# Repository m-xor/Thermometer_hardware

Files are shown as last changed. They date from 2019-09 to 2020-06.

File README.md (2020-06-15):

# Thermometer_hardware

PCBs designed for ZS60 universal case https://www.tme.eu/pl/details/z60-abs/obudowy-z-panelem/kradex/z60-abs/
The device consists of three PCB:
- LCD display board
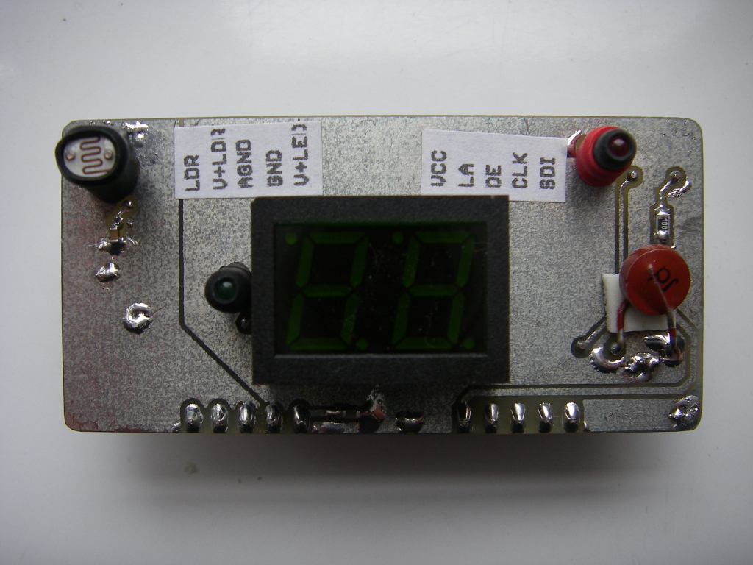
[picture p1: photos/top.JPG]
PCB top

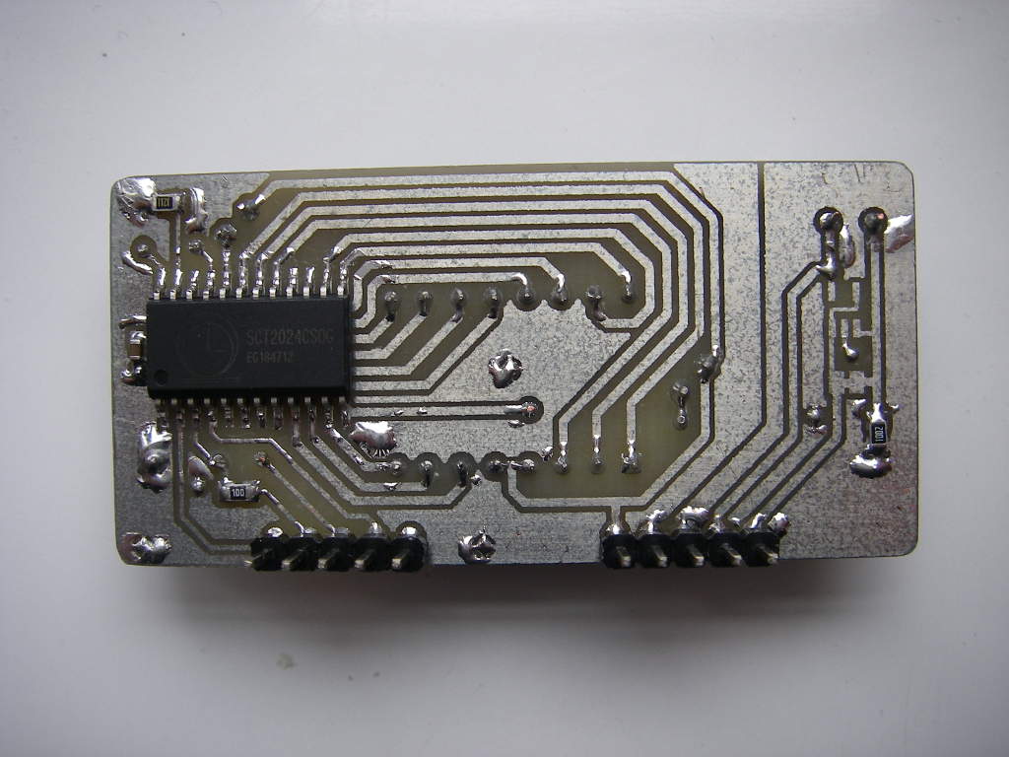
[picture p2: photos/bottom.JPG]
PCB bottom

- main board
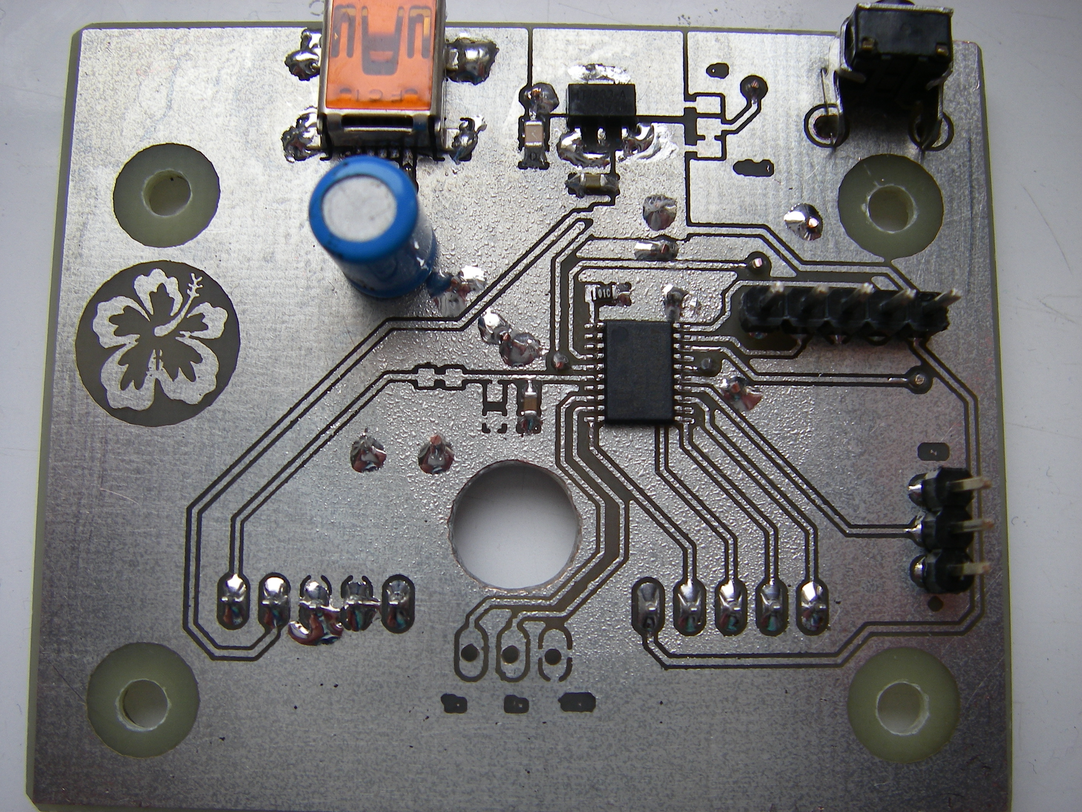
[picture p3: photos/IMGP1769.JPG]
Main board top

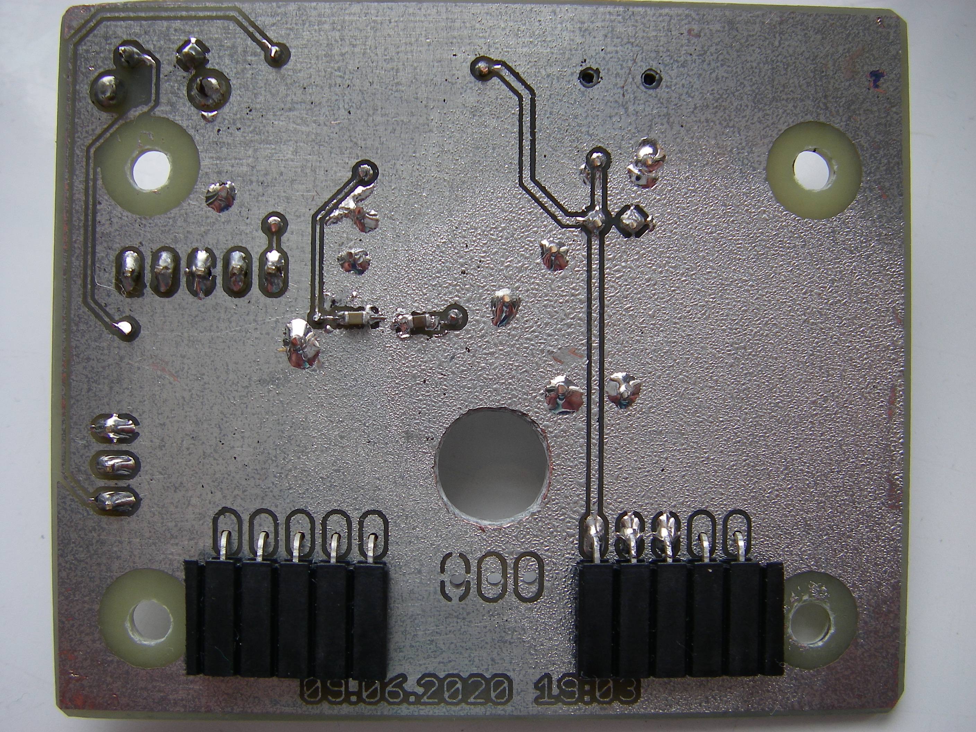
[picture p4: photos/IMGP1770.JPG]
Main board bottom

- receiver board
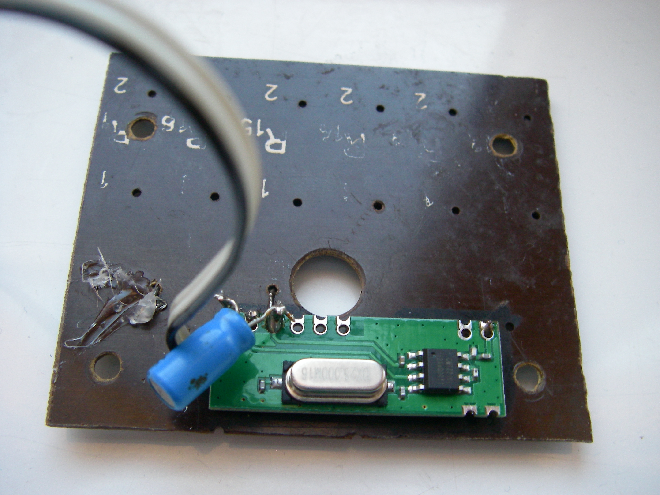
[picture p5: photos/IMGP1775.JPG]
Receiver board top

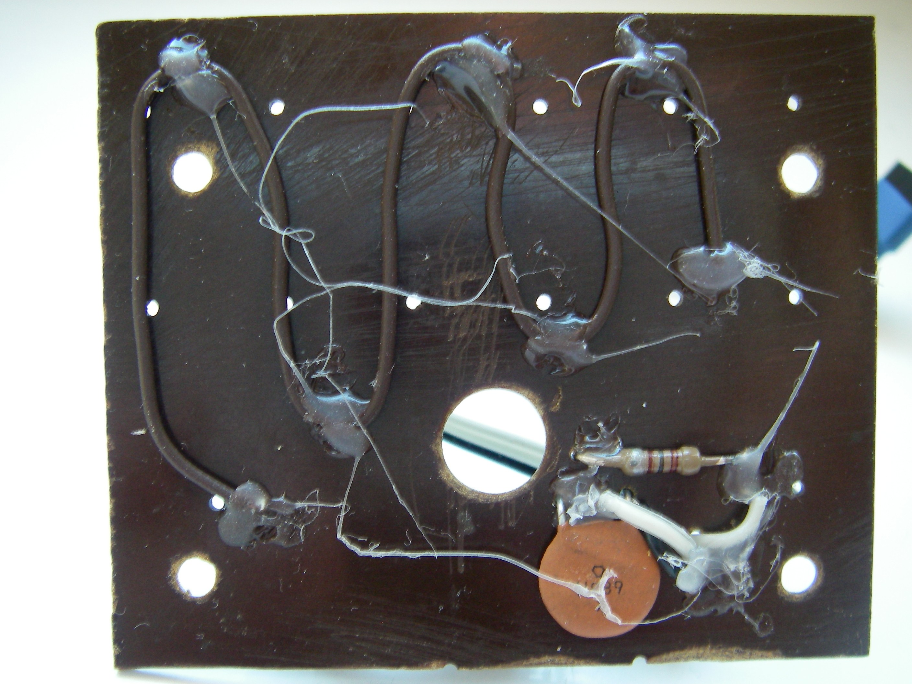
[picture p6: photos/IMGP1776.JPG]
Receiver board bottom

- The device
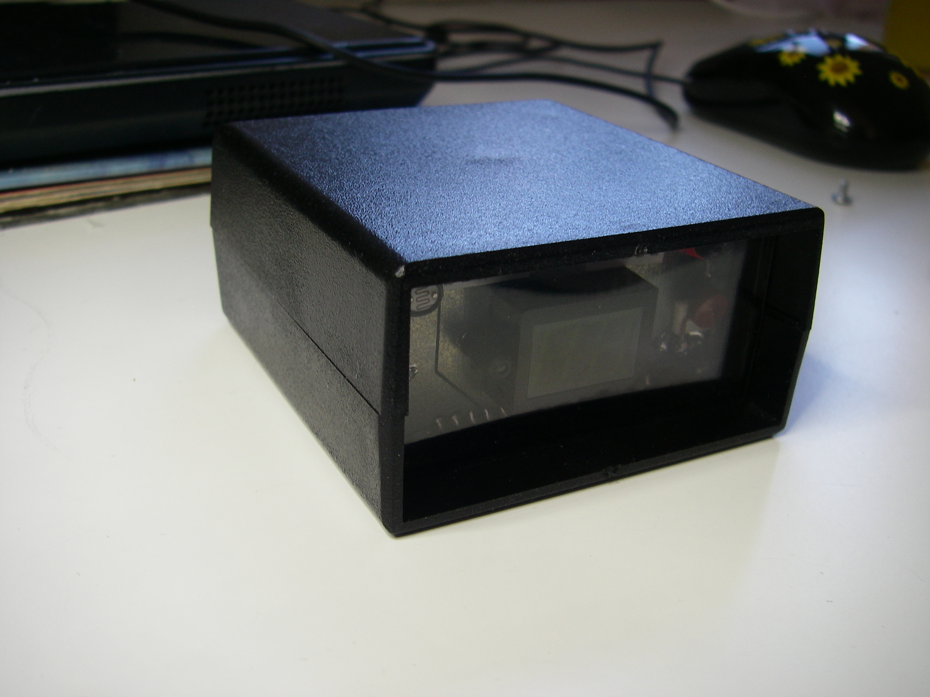
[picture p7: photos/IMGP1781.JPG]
Device


Firmware: https://github.com/m-xor/Thermometer_receiver

- Known issues
 * power socket is placed to deep
 * PA9, PA10 could be routed to solder pads in case of need accessing bootloader

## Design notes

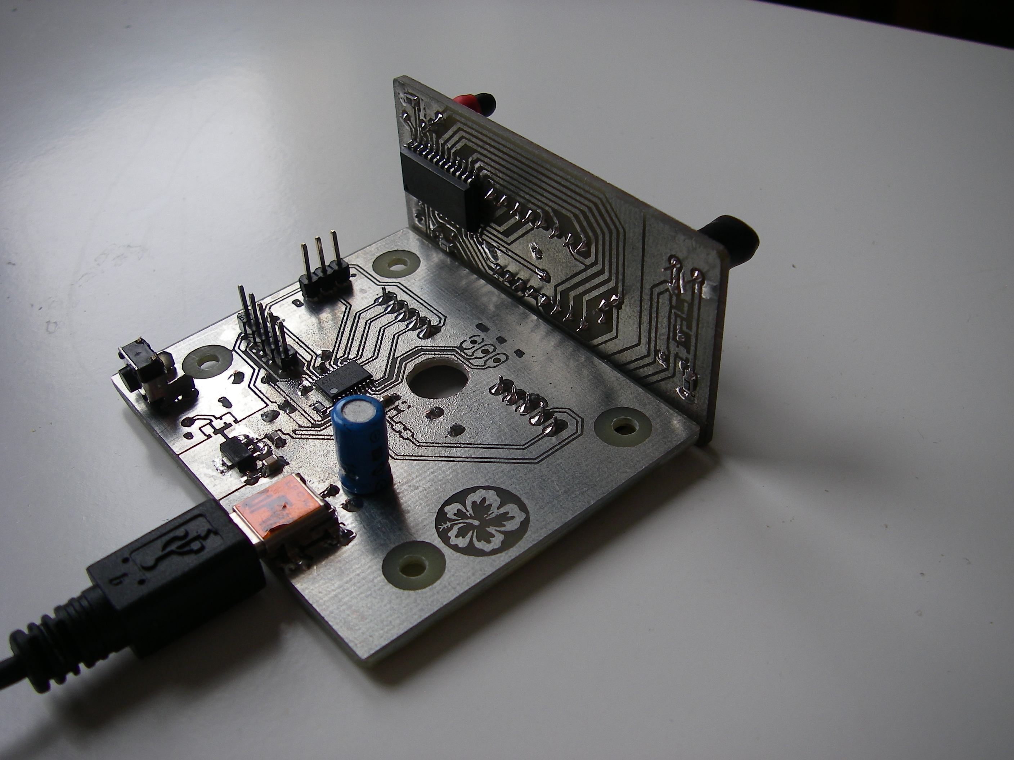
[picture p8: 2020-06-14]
photos/IMGP1772.JPG

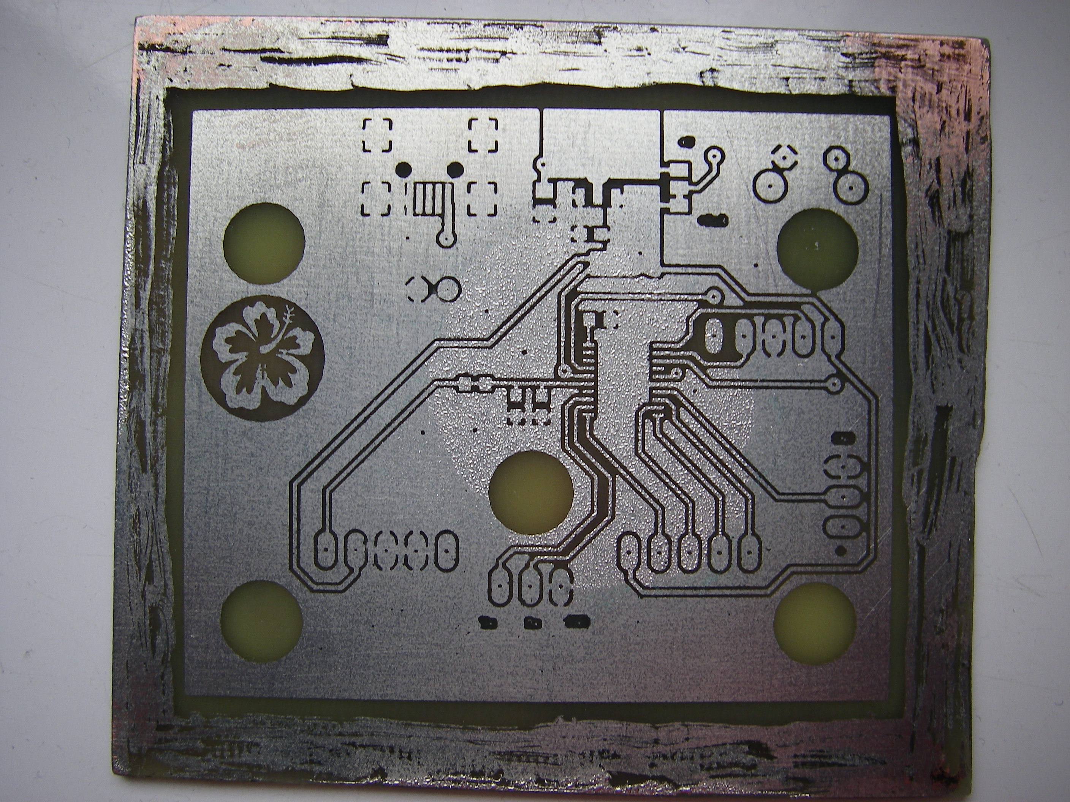
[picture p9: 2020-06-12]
photos/IMGP1759.JPG

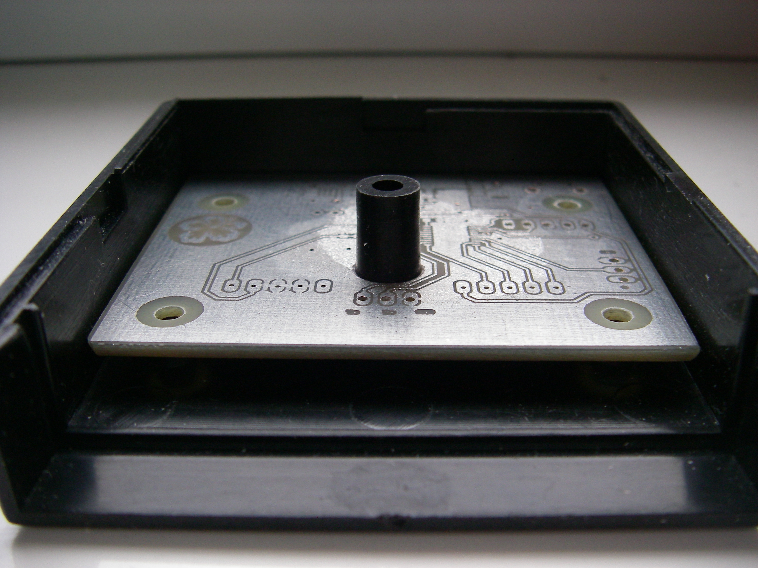
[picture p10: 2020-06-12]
photos/IMGP1766.JPG

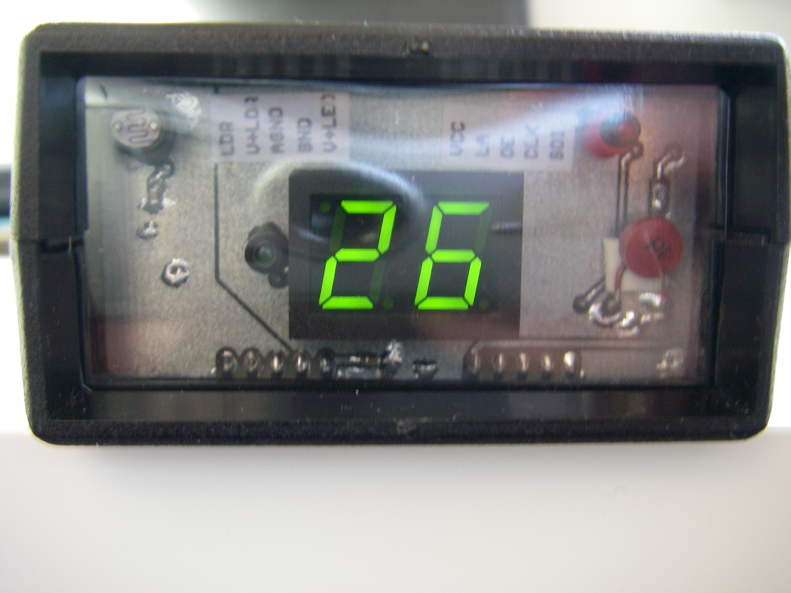
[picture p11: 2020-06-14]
photos/IMGP1783.JPG

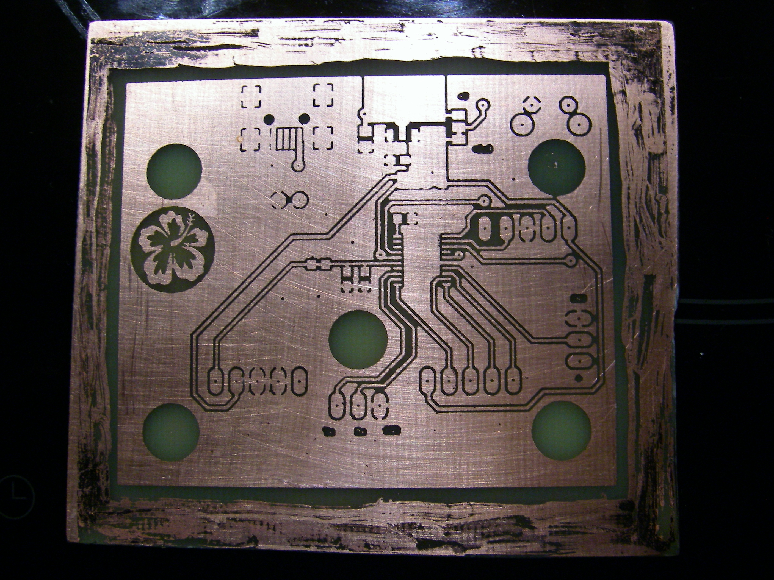
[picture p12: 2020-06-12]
photos/IMGP1753.JPG

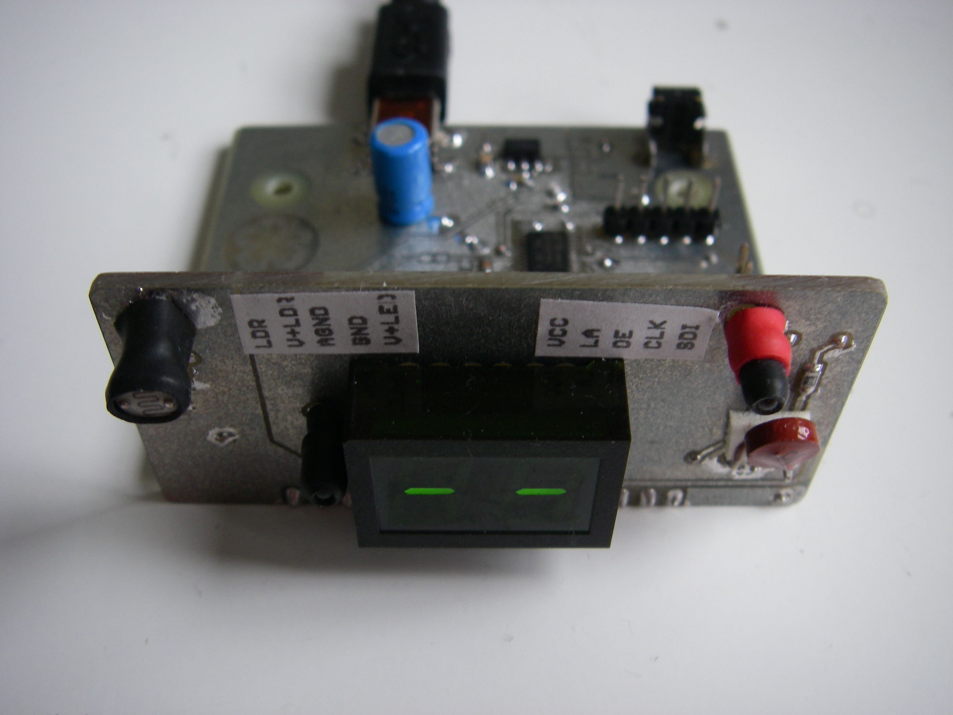
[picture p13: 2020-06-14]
photos/IMGP1771.JPG

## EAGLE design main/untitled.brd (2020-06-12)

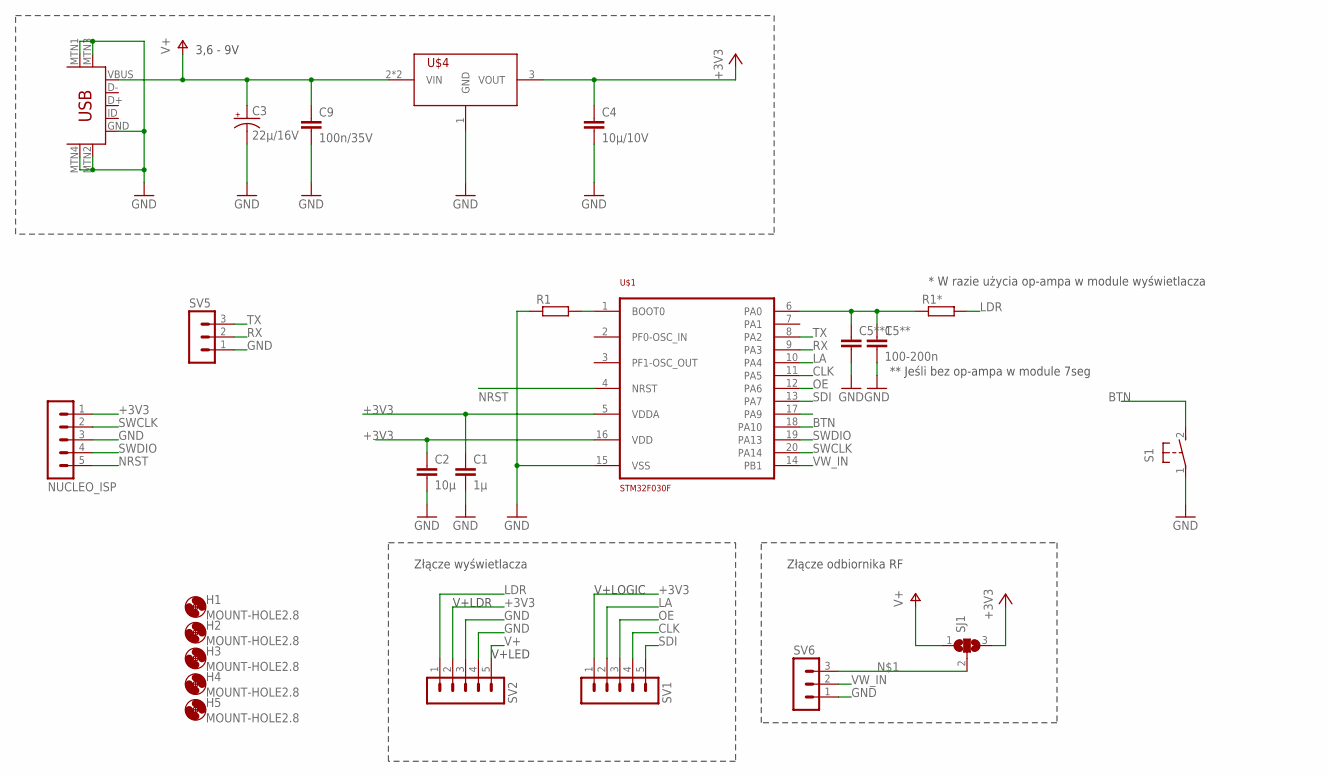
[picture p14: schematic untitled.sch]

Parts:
C1: 1µ; C0603
C2: 10µ; C0603
C3: 22µ/16V; E2,5-6
C4: 10µ/10V; C0603
C5**: 100-200n; C0603
C5**1: C-EUC0603; C0603
C9: 100n/35V; C0805
H1, H2, H3, H4, H5: MOUNT-HOLE2.8; 2,8
NUCLEO_ISP: MA05-1
R1, R1*: R-EU_R0603; R0603
S1: 31-XX; B3F-31XX
SJ1: SJ2W; SJ_2
SV1, SV2: MA05-1
SV5, SV6: MA03-1
U$1: STM32F030F; TSSOP20
U$2: USB-MINIB-5PIN; USB-MINIB
U$4: HT7333; SOT89

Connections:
+3V3: C1.1, C2.1, C4.1, NUCLEO_ISP.1, SJ1.3, SV1.1, SV2.2, U$1.5 (VDDA), U$1.16 (VDD), U$4.3 (VOUT)
BTN: S1.2 (S), U$1.18 (PA10)
CLK: SV1.4, U$1.11 (PA5)
GND: C1.2, C2.2, C3.-, C4.2, C5**.2, C5**1.2, C9.2, NUCLEO_ISP.3, R1.1, S1.1, SV2.3, SV2.4, SV5.1, SV6.1, U$1.15 (VSS), U$2.GND, U$2.MTN1 (MTN2), U$2.MTN2 (MTN3), U$2.MTN3 (MTN1), U$2.MTN4, U$4.1 (GND)
LA: SV1.2, U$1.10 (PA4)
LDR: R1*.2, SV2.1
unnamed: SJ1.2, SV6.3
unnamed: C5**.1, C5**1.1, R1*.1, U$1.6 (PA0)
unnamed: R1.2, U$1.1 (BOOT0)
NRST: NUCLEO_ISP.5, U$1.4 (NRST)
OE: SV1.3, U$1.12 (PA6)
RX: SV5.2, U$1.9 (PA3)
SDI: SV1.5, U$1.13 (PA7)
SWCLK: NUCLEO_ISP.2, U$1.20 (PA14)
SWDIO: NUCLEO_ISP.4, U$1.19 (PA13)
TX: SV5.3, U$1.8 (PA2)
V+: C3.+, C9.1, SJ1.1, SV2.5, U$2.VBUS, U$4.2 (VIN), U$4.2.1 (VIN)
VW_IN: SV6.2, U$1.14 (PB1)

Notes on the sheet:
* W razie użycia op-ampa w module wyświetlacza
** Jeśli bez op-ampa w module 7seg
3,6 - 9V
Złącze wyświetlacza
Złącze odbiornika RF
V+LDR
V+LED
V+LOGIC

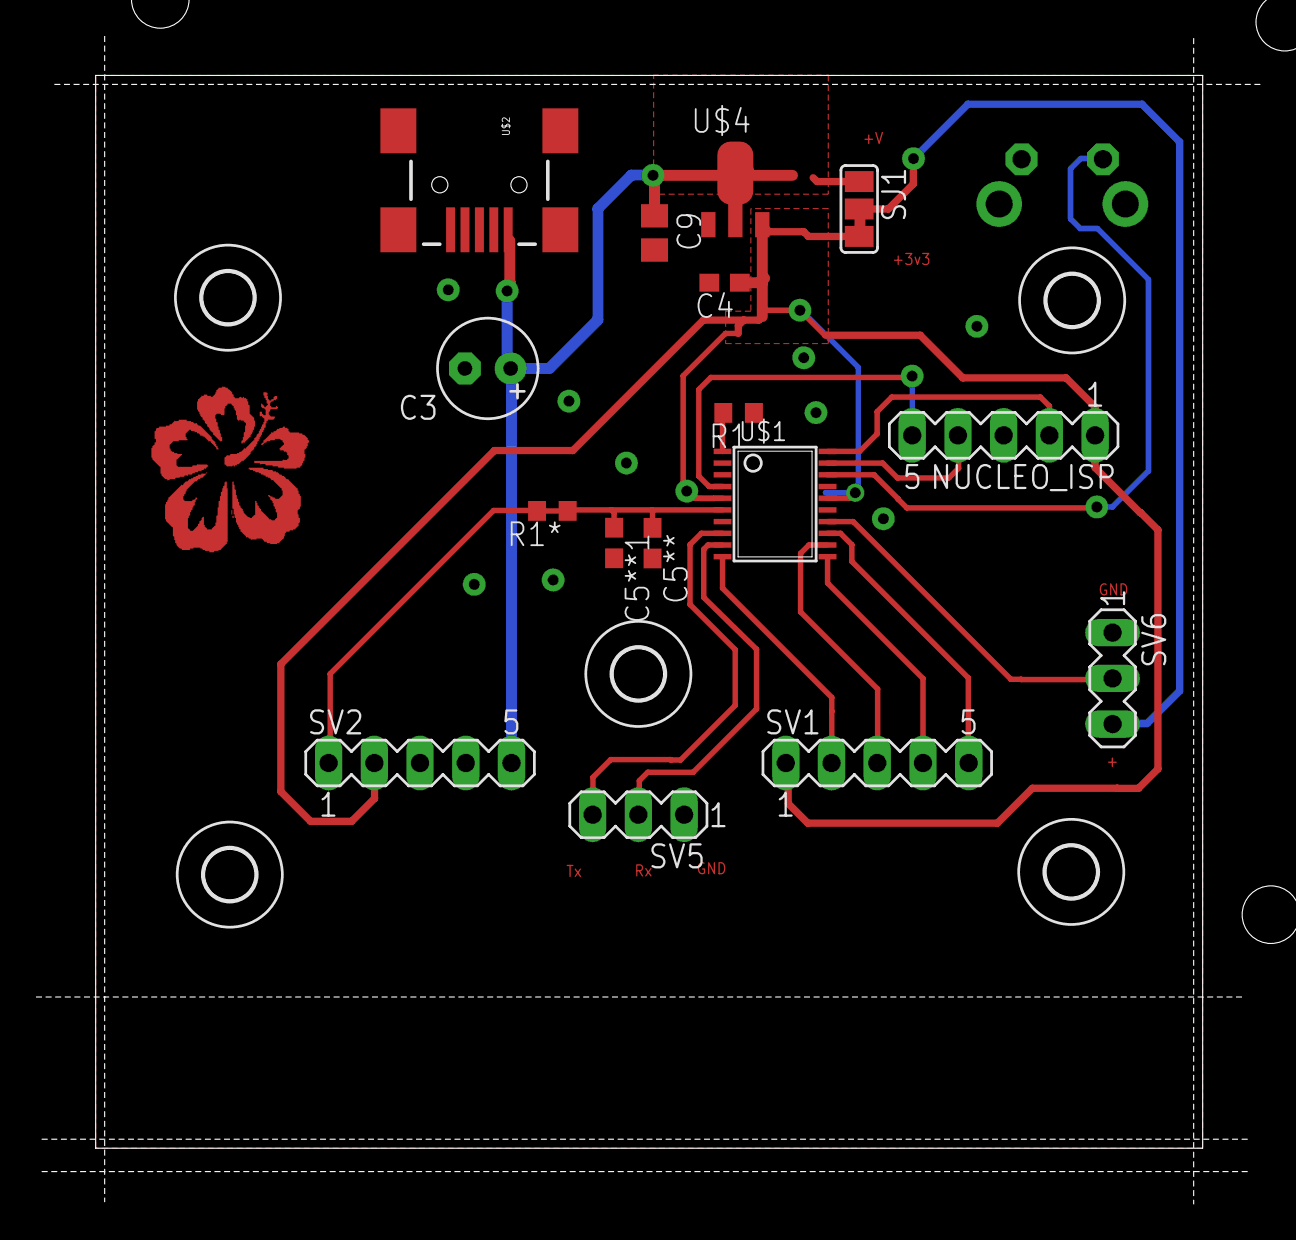
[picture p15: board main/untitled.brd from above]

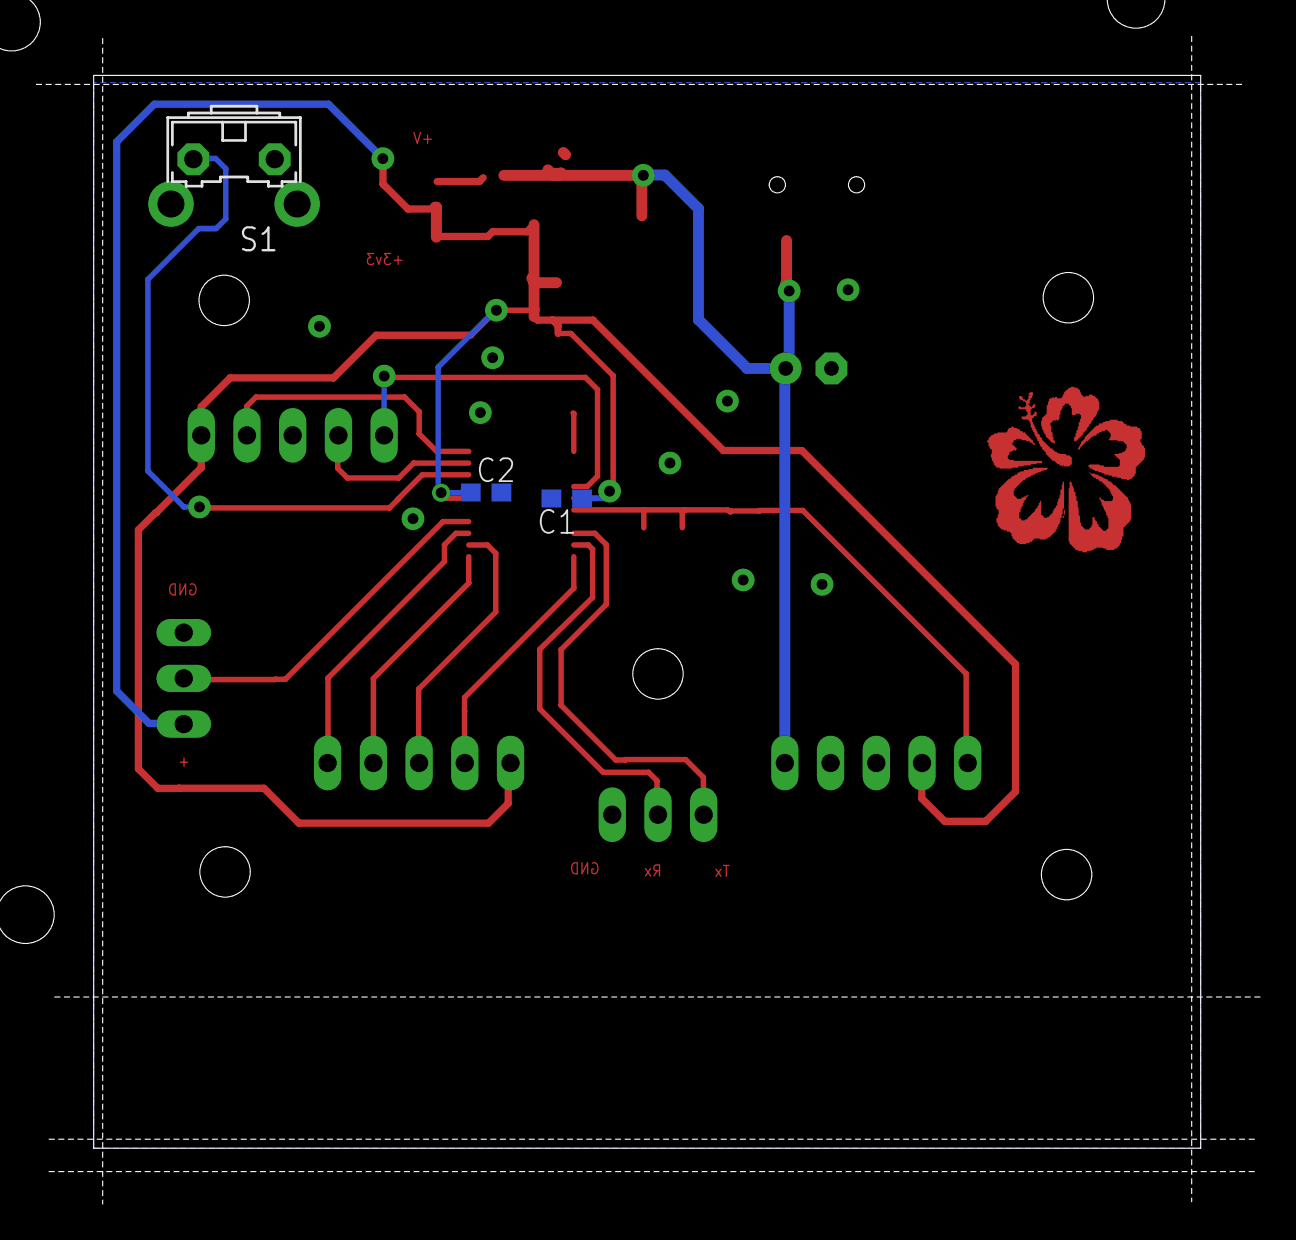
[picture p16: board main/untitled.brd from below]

Board: 2 copper layers, 61.5 x 59.6 mm, 26 parts (4 on the bottom side), 18 nets.

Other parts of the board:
DRILEGEND: DRILEGEND
U$3: LOGO_SMALL

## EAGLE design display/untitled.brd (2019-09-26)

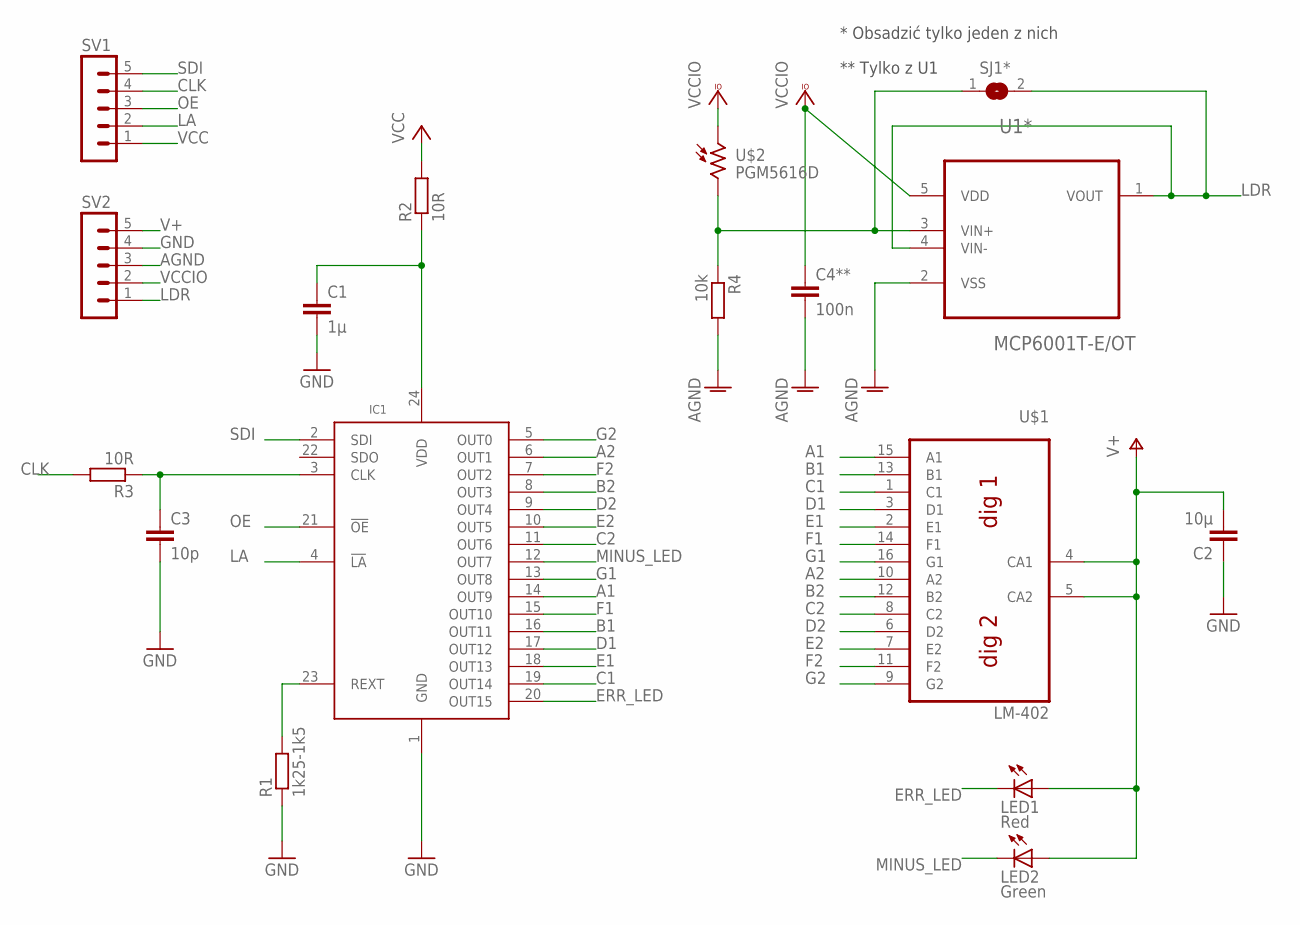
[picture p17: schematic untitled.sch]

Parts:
C1: 1µ; C0603K
C2: 10µ; C0603K
C3: 10p; C050-030X075
C4**: 100n; C0603K
IC1: SCT24; SSOP24
LED1: Red; LED3MM
LED2: Green; LED3MM
R1: 1k25-1k5; M0805
R2: 10R; R0805
R3: 10R; M0805
R4: 10k; M0805
SJ1*: SJ
SV1, SV2: MA05-1
U1*: MCP6001T-E/OT; SOT95P270X145-5N
U$1: LB-402
U$2: PGM5616D; PHOTO_5_34

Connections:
A1: IC1.14 (OUT9), U$1.15 (A1)
A2: IC1.6 (OUT1), U$1.10 (A2)
AGND: C4**.2, R4.2, SV2.3, U1*.2 (VSS)
B1: IC1.16 (OUT11), U$1.13 (B1)
B2: IC1.8 (OUT3), U$1.12 (B2)
C1: IC1.19 (OUT14), U$1.1 (C1)
C2: IC1.11 (OUT6), U$1.8 (C2)
CLK: R3.2, SV1.4
D1: IC1.17 (OUT12), U$1.3 (D1)
D2: IC1.9 (OUT4), U$1.6 (D2)
E1: IC1.18 (OUT13), U$1.2 (E1)
E2: IC1.10 (OUT5), U$1.7 (E2)
ERR_LED: IC1.20 (OUT15), LED1.K (C)
F1: IC1.15 (OUT10), U$1.14 (F1)
F2: IC1.7 (OUT2), U$1.11 (F2)
G1: IC1.13 (OUT8), U$1.16 (G1)
G2: IC1.5 (OUT0), U$1.9 (G2)
GND: C1.2, C2.1, C3.2, IC1.1 (GND), R1.1, SV2.4
LA: IC1.4 (!LA), SV1.2
LDR: SJ1*.2, SV2.1, U1*.1 (VOUT), U1*.4 (VIN-)
MINUS_LED: IC1.12 (OUT7), LED2.K (C)
unnamed: C1.1, IC1.24 (VDD), R2.1
unnamed: IC1.23 (REXT), R1.2
unnamed: C3.1, IC1.3 (CLK), R3.1
unnamed: R4.1, SJ1*.1, U1*.3 (VIN+), U$2.2
OE: IC1.21 (!OE), SV1.3
SDI: IC1.2 (SDI), SV1.5
V+: C2.2, LED1.A, LED2.A, SV2.5, U$1.4 (CA1), U$1.5 (CA2)
VCC: R2.2, SV1.1
VCCIO: C4**.1, SV2.2, U1*.5 (VDD), U$2.1

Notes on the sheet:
* Obsadzić tylko jeden z nich
** Tylko z U1

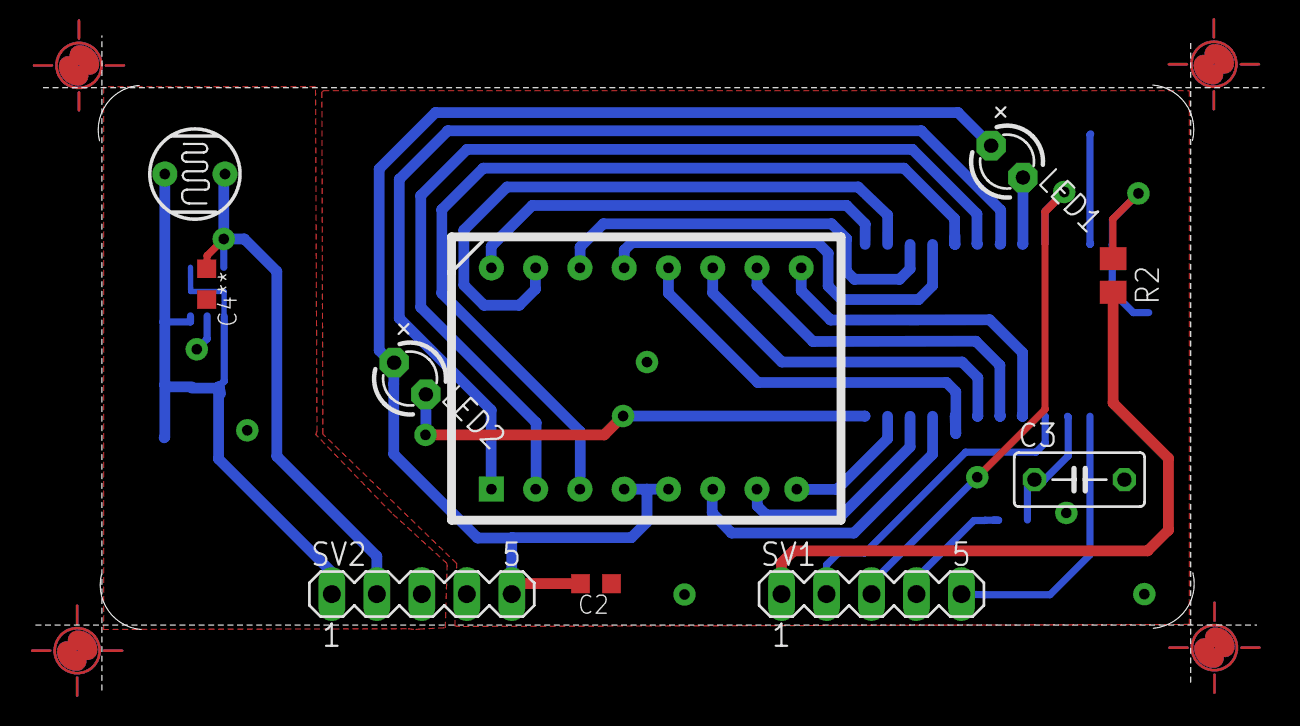
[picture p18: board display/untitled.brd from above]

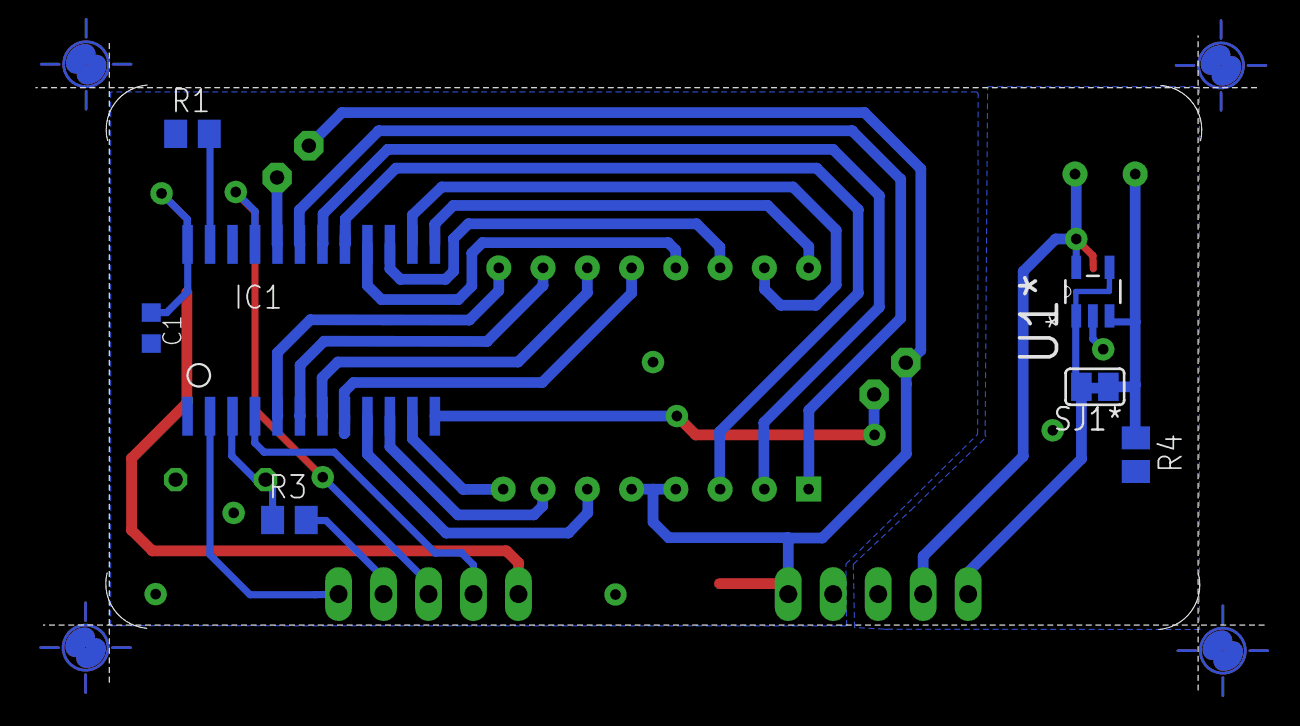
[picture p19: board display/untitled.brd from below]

Board: 2 copper layers, 69.4 x 37.0 mm, 22 parts (7 on the bottom side), 30 nets.

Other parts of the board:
DRILEGEND: DRILEGEND
U$3, U$4, U$5, U$6: PASS-ROUND

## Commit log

2020-06-12 ultimate version
    [untitled.brd, untitled.sch]
2020-06-14 main board's assembly

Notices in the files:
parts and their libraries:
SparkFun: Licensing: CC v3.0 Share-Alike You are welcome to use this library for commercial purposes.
